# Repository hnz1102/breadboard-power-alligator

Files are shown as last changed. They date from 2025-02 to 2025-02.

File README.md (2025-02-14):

<div align="center">
  <h1><code>BREAD BOARD POWER ALLIGATOR</code></h1>
  <p>
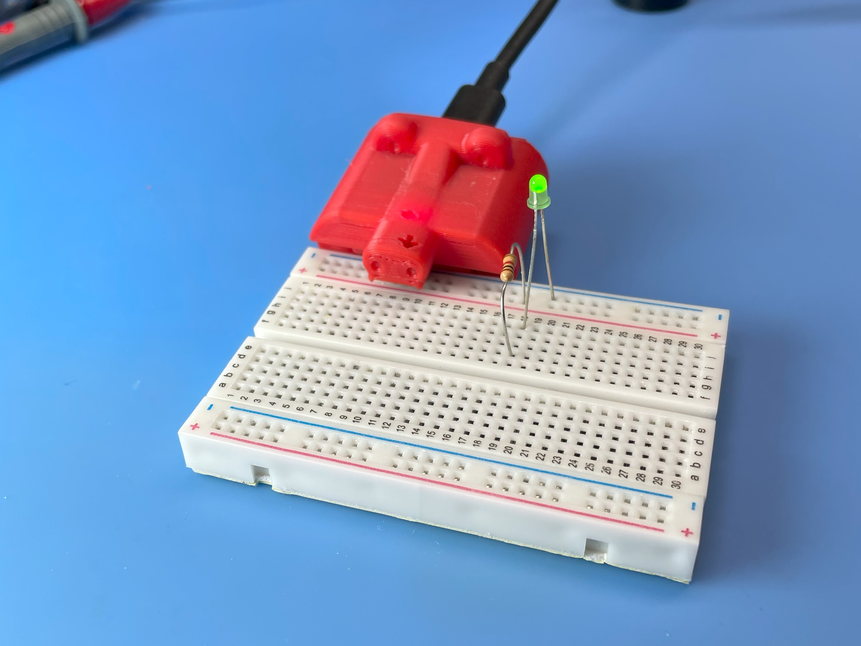
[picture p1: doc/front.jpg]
    
  </p>
</div>

# BREAD BOARD POWER ALLIGATOR : Power Supply for Bread-Board

This is power supplies for bread-board. They are designed to be used with a USB PD power supply. The output voltage is from 3.3V to 20V, and the output current is maximum 1A. The output voltage is fixed each adoptor. I made 6 adapters for bread-board power supply. The adapters are 3.3V, 5V, 9V, 12V, 15V, and 20V. The adapters are connected to the bread-board such an alligator clips. It is easy to set up the power supply for the bread-board. If you use a USB PD power supply, you can use over 9V output. If it is not USB PD, you can use only 3.3V or 5V.

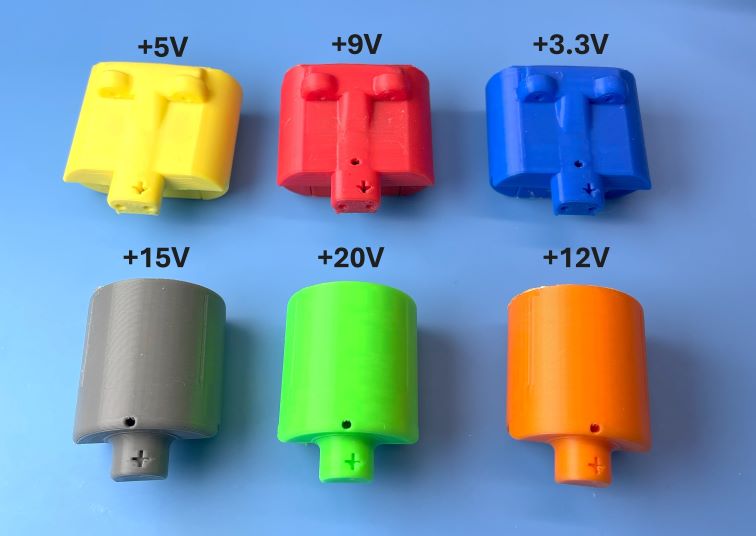
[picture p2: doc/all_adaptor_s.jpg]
All adapters


The PCB is designed by KiCad. The PCB is common to all adapters. 

## How to use
Just connect a USB PD power supply to the USB-C connector. Then, connect the adoptor to the bread-board. The output voltage is fixed each adoptor. If it turns on the power supply, the LED lights up. 

Be careful to connect the adoptor to the bread-board. The inside of the bread-board power line is +, so connect it so that the top is -. Also, be careful not to connect different adapters to the same bread-board.

## Schematic
[Schematic PDF File](doc/schematic.pdf)

Each adoptor has a different output voltage. The output voltage is determined by any of the following parts.

|Output Voltage|U102|D102|C101|C104|R103|R104|R105|R106|JP101|JP102|
|---|---|--|--|--|--|--|--|--|--|--|
|3.3V|AZ1117CH-3.3|CUS10F3D|DNP|10uF|1K|DNP|0|DNP|OPEN|SHUNT|
|5V|DNP|DNP|DNP|DNP|1K|DNP|DNP|DNP|SHUNT|SHUNT|
|9V|DNP|DNP|1uF|DNP|2K|1K|DNP|20K|SHUNT|OPEN|
|12V|DNP|DNP|1uF|DNP|2K|1K|DNP|47K|SHUNT|OPEN|
|15V|DNP|DNP|1uF|DNP|2K|1K|DNP|100K|SHUNT|OPEN|
|20V|DNP|DNP|1uF|DNP|2K|1K|DNP|200K|SHUNT|OPEN|

*1 DNP: Do Not Populate
*2 R107 is DNP for all adapters.

If you want to change the output voltage, you can change the parts of the table.
e.g If you want to change the output voltage to 1.8V or 2.5V, you can change the parts as follows.
|Output Voltage|U102|D102|C101|C104|R103|R104|R105|R106|JP101|JP102|
|---|---|--|--|--|--|--|--|--|--|--|
|1.8V|AZ1117CH-1.8|CUS10F3D|DNP|10uF|1K|DNP|0|DNP|OPEN|SHUNT|
|2.5V|AZ1117CH-2.5|CUS10F3D|DNP|10uF|1K|DNP|0|DNP|OPEN|SHUNT|

## PCB

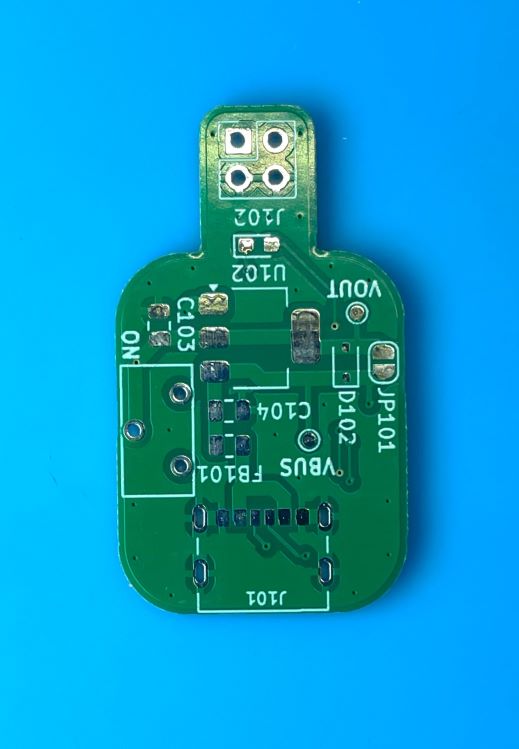
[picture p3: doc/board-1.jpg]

*3 In the photo, the PCB is designed to accommodate a Switch, but it was removed from the PCB layout because a compatible Switch could not be found.

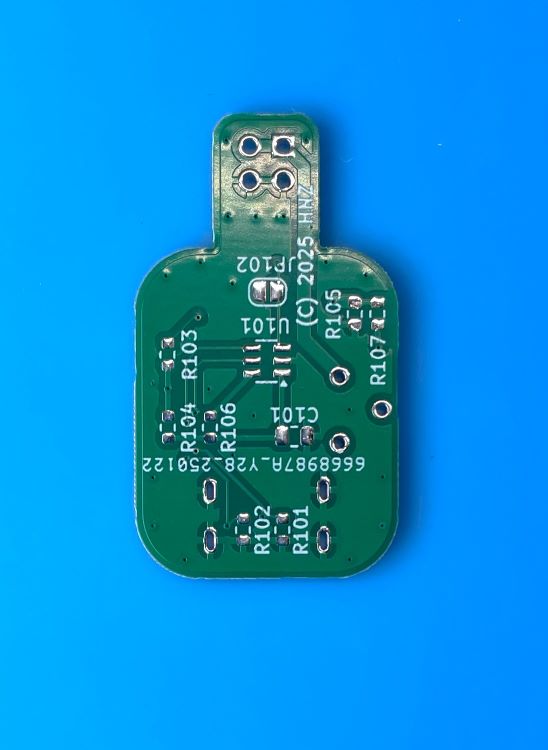
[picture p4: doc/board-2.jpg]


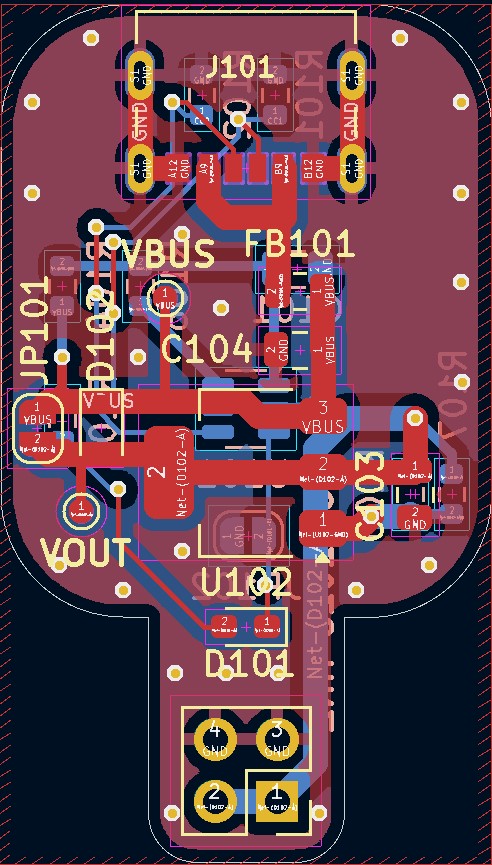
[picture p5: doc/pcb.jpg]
PCB Layout


# Container

There are STL data for 3D printer in the `stl` directory.
bottom.stl is the bottom of the container. upper-al-xx.stl is the upper of the container like alligator clips. upper-simple_xx.stl is the upper of the container like a battery form.

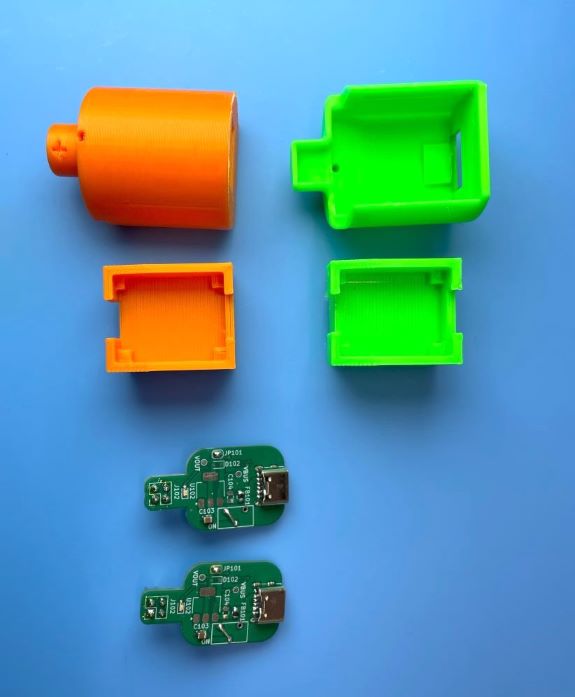
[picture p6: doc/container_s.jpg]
Container


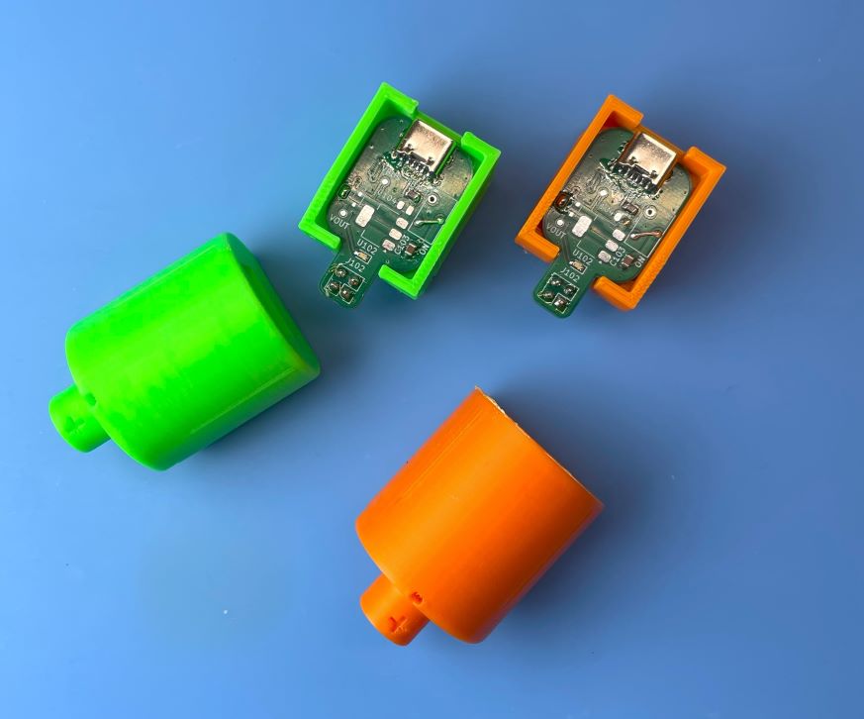
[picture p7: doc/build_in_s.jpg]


## LICENSE
Hardware Schematic Documents are licensed under CC-BY-SA V4.0.

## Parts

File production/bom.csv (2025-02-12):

Reference | Value | Footprint | Qty | digikey | distributor
C101 | 1uF/50V | Capacitor_SMD:C_0805_2012Metric | 1 | 311-1886-1-ND | https://www.digikey.com/en/products/detail/yageo/CC0805KKX7R9BB105/5195292
C103 | 22uF | Capacitor_SMD:C_0805_2012Metric | 1 | 311-1903-1-ND | https://www.digikey.com/en/products/detail/yageo/CC0805MKX5R8BB226/5195309
C104 | 10uF | Capacitor_SMD:C_0805_2012Metric | 1 | 311-1869-1-ND | https://www.digikey.com/en/products/detail/yageo/CC0805KKX5R8BB106/5195275
D101 | LED RED | LED_SMD:LED_0603_1608Metric_Pad1.05x0.95mm_HandSolder | 1 | 3147-B1931URO-20D000114U1930CT-ND | https://www.digikey.com/en/products/detail/harvatek-corporation/B1931URO-20D000114U1930/15910603
D102 | CUS10F30 | Diode_SMD:D_SOD-323 | 1 | CUS10F30H3FCT-ND | https://www.digikey.com/en/products/detail/toshiba-semiconductor-and-storage/CUS10F30-H3F/2753202
FB101 | MPZ2012S102ATD25 | Resistor_SMD:R_0805_2012Metric | 1 | 445-MPZ2012S102ATD25CT-ND | https://www.digikey.com/en/products/detail/tdk-corporation/MPZ2012S102ATD25/5040327
J101 | USB_C_Receptacle_PowerOnly_6P | Library:CUI_UJC-HP-3-SMT-TR | 1 | 2223-UJC-HP-3-SMT-CT-ND | https://www.digikey.com/en/products/detail/same-sky-formerly-cui-devices/UJC-HP-3-SMT-TR/12173295
J102 | PinHeader 02x02 | Connector_PinHeader_2.54mm:PinHeader_2x02_P2.54mm_Vertical | 1 | 2057-PH2-04-UA-ND | https://www.digikey.com/en/products/detail/adam-tech/PH2-04-UA/9830324
JP101 | SHUNT IT IF NO USE AZ117C | Jumper:SolderJumper-2_P1.3mm_Open_RoundedPad1.0x1.5mm | 1 | - | -
JP102 | SHUNT IT IF NO USE CH221K | Jumper:SolderJumper-2_P1.3mm_Open_RoundedPad1.0x1.5mm | 1 | - | -
R101,R102 | 5K1 | Resistor_SMD:R_0603_1608Metric | 2 | 311-5.10KHRCT-ND | https://www.digikey.com/en/products/detail/yageo/RC0603FR-075K1L/727268
R103 | 2K | Resistor_SMD:R_0603_1608Metric | 1 | 311-2.0KGRCT-ND | https://www.digikey.com/en/products/detail/yageo/RC0603JR-072KL/726726
R104 | 1K | Resistor_SMD:R_0603_1608Metric | 1 | 311-1.00KHRCT-ND | https://www.digikey.com/en/products/detail/yageo/RC0603FR-071KL/726843
R105 | 0/ADJ-R2 | Resistor_SMD:R_0603_1608Metric | 1 | 311-0.0GRCT-ND | https://www.digikey.com/en/products/detail/yageo/RC0603JR-070RL/726675
R106 | 200K | Resistor_SMD:R_0603_1608Metric | 1 | 311-200KHRCT-ND | https://www.digikey.com/en/products/detail/yageo/RC0603FR-07200KL/727044
R107 | ADJ-R1 | Resistor_SMD:R_0603_1608Metric | 1 | - | -
TP101 | VOUT | TestPoint:TestPoint_Pad_D1.0mm | 1 | - | -
TP102 | VBUS | TestPoint:TestPoint_Pad_D1.0mm | 1 | - | -
U101 | CH221K | Package_TO_SOT_SMD:SOT-23-6 | 1 | - | https://jlcpcb.com/partdetail/WCH_Nanjing_Qinheng-CH221K/C5125736
U102 | AZ1117C | Package_TO_SOT_SMD:SOT-223-3_TabPin2 | 1 | 497-17239-1-ND | https://www.digikey.com/en/products/detail/stmicroelectronics/LD1117S33TR/585766

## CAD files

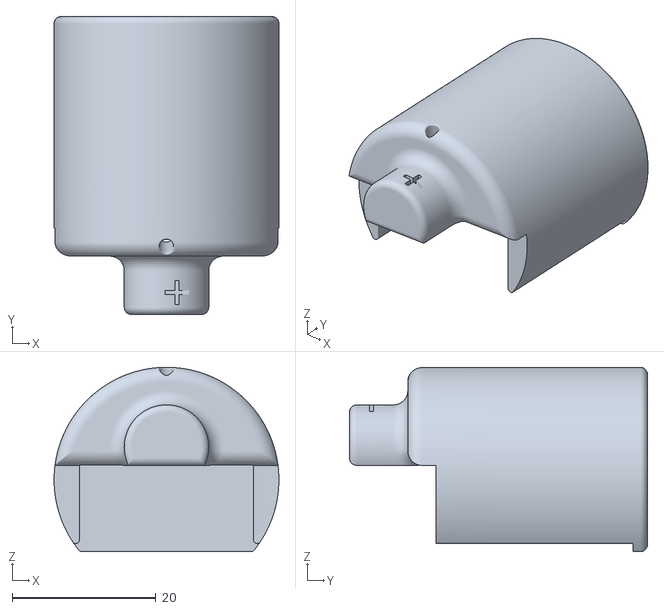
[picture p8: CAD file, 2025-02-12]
stl/upper_simple_15v.stl
31.2 x 41.4 x 25.6

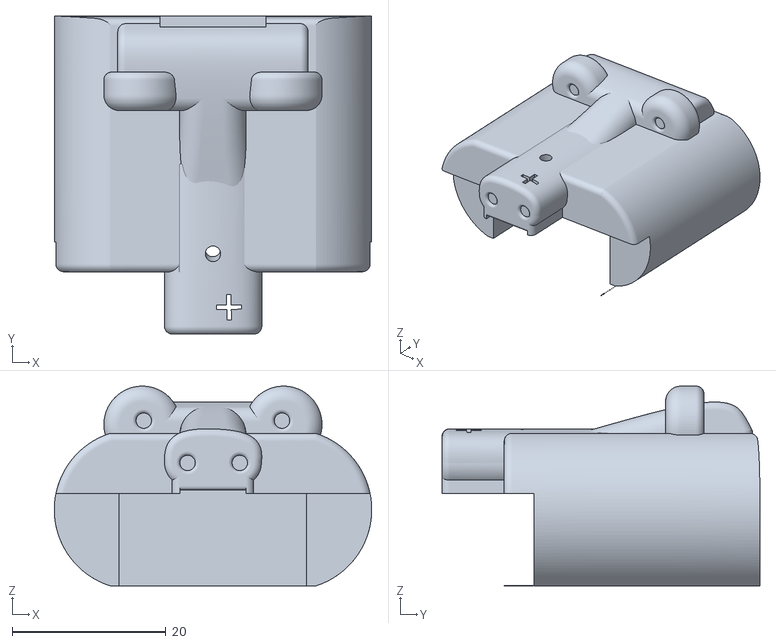
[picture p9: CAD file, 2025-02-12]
stl/upper-al-12v.stl
41.3 x 41.4 x 26.0

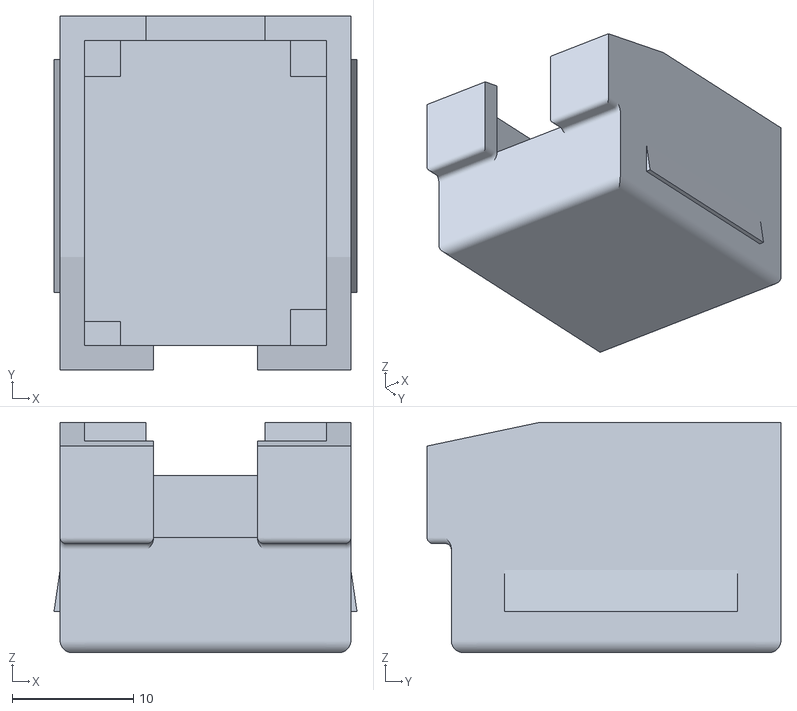
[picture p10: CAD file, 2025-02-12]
stl/bottom.stl
25.0 x 29.2 x 19.0

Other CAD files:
stl/upper_simple_12v.stl
stl/upper-simple-5v.stl
stl/upper-simple-3.3v.stl
stl/upper-simple-9v.stl
stl/upper-al-20v.stl
stl/upper-al-9v.stl
stl/upper-al-15v.stl
stl/upper-al-3.3v.stl
stl/upper-simple-20v.stl
stl/upper-al-5v.stl

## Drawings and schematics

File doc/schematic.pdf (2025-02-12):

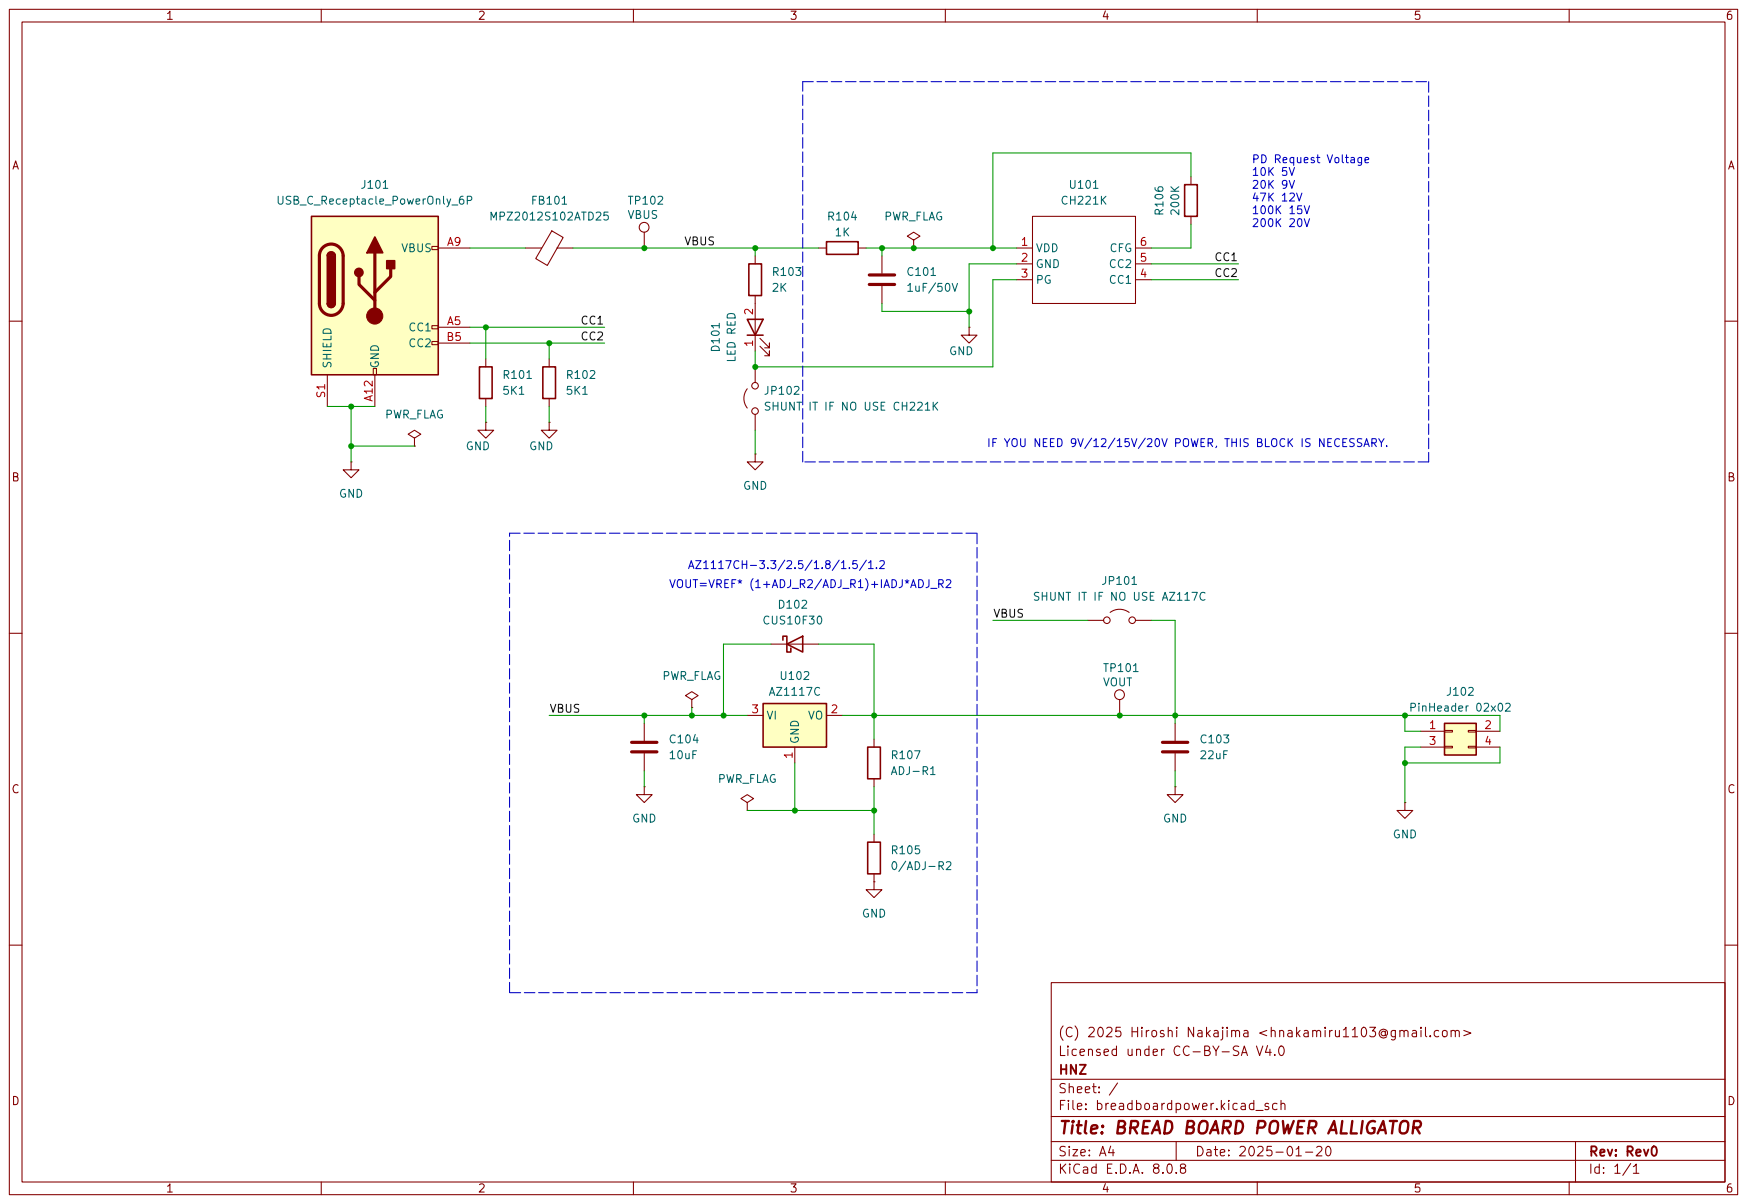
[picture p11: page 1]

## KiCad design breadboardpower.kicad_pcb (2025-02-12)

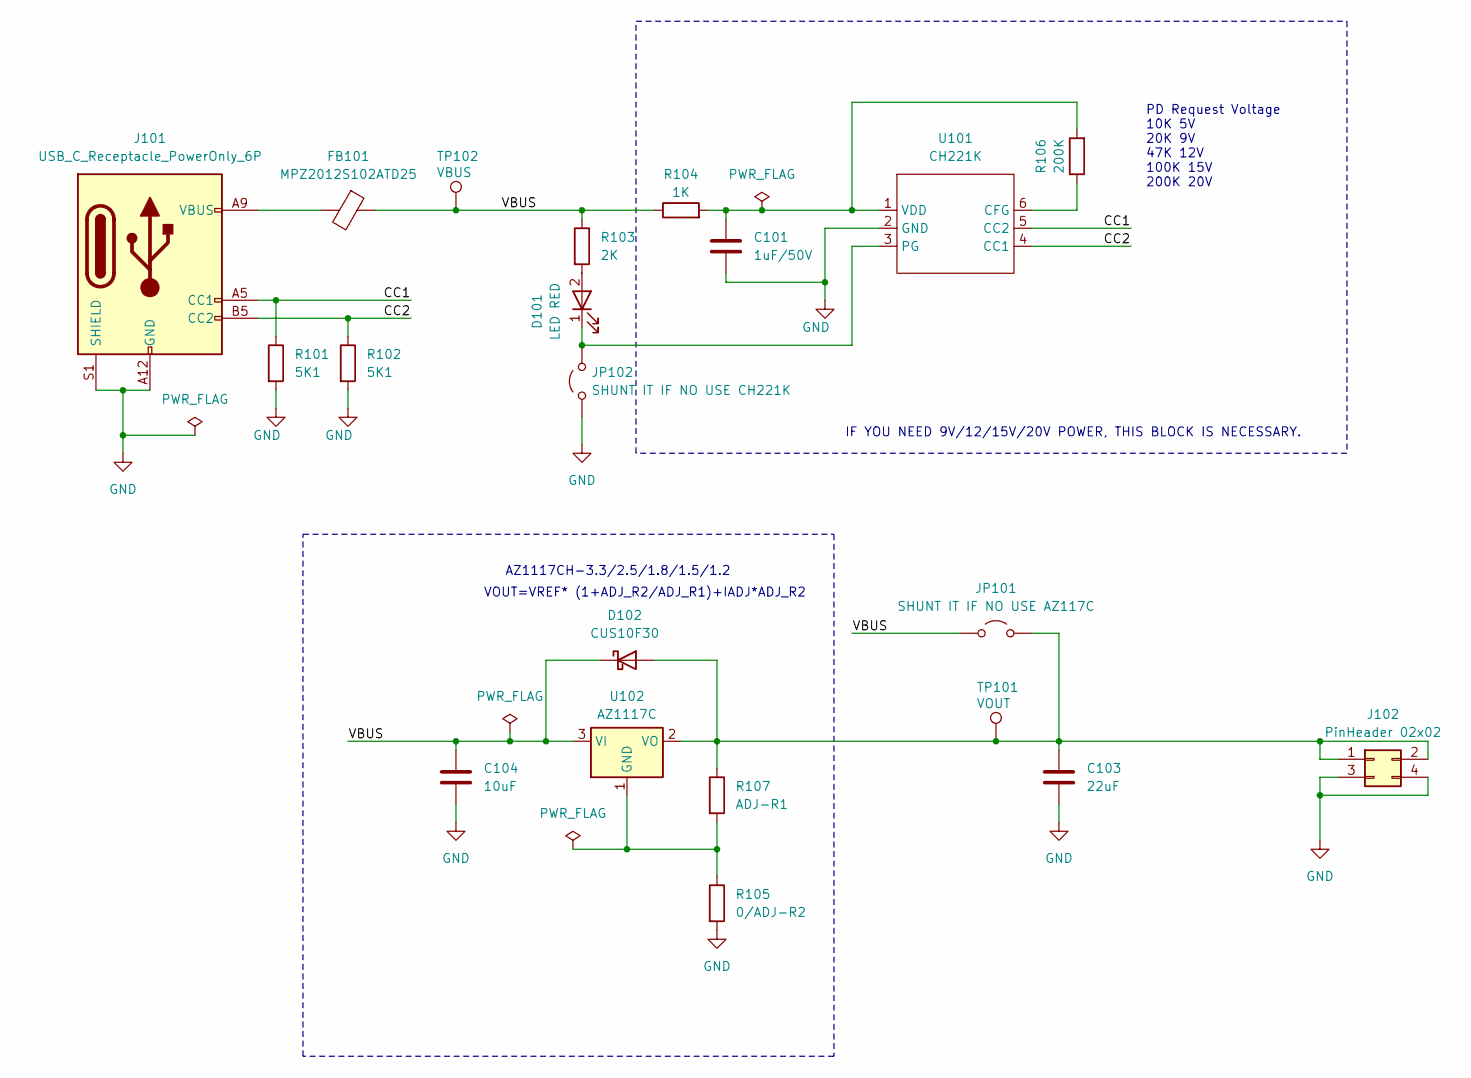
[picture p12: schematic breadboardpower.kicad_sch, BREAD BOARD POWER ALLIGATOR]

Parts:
C101: 1uF/50V; C_0805_2012Metric; digikey 311-1886-1-ND
C103: 22uF; C_0805_2012Metric; digikey 311-1903-1-ND
C104: 10uF; C_0805_2012Metric; digikey 311-1869-1-ND
D101: LED RED; LED_0603_1608Metric_Pad1.05x0.95mm_HandSolder; digikey 3147-B1931URO-20D000114U1930CT-ND
D102: CUS10F30; D_SOD-323; digikey CUS10F30H3FCT-ND
FB101: MPZ2012S102ATD25; R_0805_2012Metric; digikey 445-MPZ2012S102ATD25CT-ND
J101: USB_C_Receptacle_PowerOnly_6P; CUI_UJC-HP-3-SMT-TR; digikey 2223-UJC-HP-3-SMT-CT-ND
J102: PinHeader 02x02; PinHeader_2x02_P2.54mm_Vertical; digikey 2057-PH2-04-UA-ND
JP101: SHUNT IT IF NO USE AZ117C; SolderJumper-2_P1.3mm_Open_RoundedPad1.0x1.5mm
JP102: SHUNT IT IF NO USE CH221K; SolderJumper-2_P1.3mm_Open_RoundedPad1.0x1.5mm
R101, R102: 5K1; R_0603_1608Metric; digikey 311-5.10KHRCT-ND
R103: 2K; R_0603_1608Metric; digikey 311-2.0KGRCT-ND
R104: 1K; R_0603_1608Metric; digikey 311-1.00KHRCT-ND
R105: 0/ADJ-R2; R_0603_1608Metric; digikey 311-0.0GRCT-ND
R106: 200K; R_0603_1608Metric; digikey 311-200KHRCT-ND
R107: ADJ-R1; R_0603_1608Metric
TP101: VOUT; TestPoint_Pad_D1.0mm
TP102: VBUS; TestPoint_Pad_D1.0mm
U101: CH221K; SOT-23-6
U102: AZ1117C; SOT-223-3_TabPin2; digikey 497-17239-1-ND

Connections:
/CC1: J101.A5 (CC1), R101.1, U101.5 (CC2)
/CC2: J101.B5 (CC2), R102.1, U101.4 (CC1)
/VBUS: C104.1, D102.1 (K), FB101.1, JP101.1 (A), R103.1, R104.1, TP102.1, U102.3 (VI)
GND: C101.2, C103.2, C104.2, J101.A12 (GND), J101.B12 (GND), J101.S1 (SHIELD), J102.3, J102.4, JP102.1 (A), R101.2, R102.2, R105.2, U101.2 (GND)
unnamed: D101.2 (A), R103.2
unnamed: D101.1 (K), JP102.2 (B), U101.3 (PG)
unnamed: C103.1, D102.2 (A), J102.1, J102.2, JP101.2 (B), R107.1, TP101.1, U102.2 (VO)
unnamed: FB101.2, J101.A9 (VBUS), J101.B9 (VBUS)
unnamed: R106.1, U101.6 (CFG)
unnamed: C101.1, R104.2, R106.2, U101.1 (VDD)
unnamed: R105.1, R107.2, U102.1 (GND)

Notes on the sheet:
VOUT=VREF* (1+ADJ_R2/ADJ_R1)+IADJ*ADJ_R2
IF YOU NEED 9V/12/15V/20V POWER, THIS BLOCK IS NECESSARY.
PD Request Voltage 10K 5V 20K 9V 47K 12V 100K 15V 200K 20V
AZ1117CH-3.3/2.5/1.8/1.5/1.2

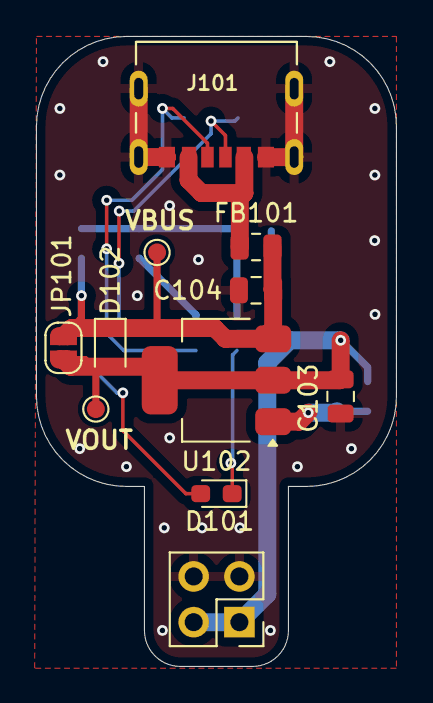
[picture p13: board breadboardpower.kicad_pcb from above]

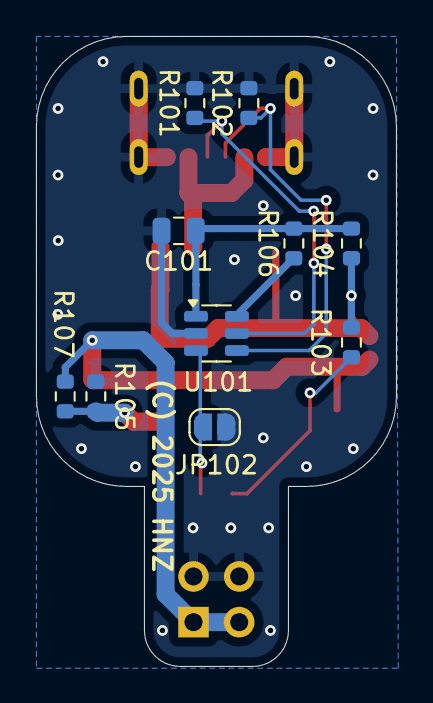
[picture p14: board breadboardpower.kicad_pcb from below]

Board: 2 copper layers, 20.0 x 35.0 mm, 21 parts (10 on the bottom side), 11 nets.

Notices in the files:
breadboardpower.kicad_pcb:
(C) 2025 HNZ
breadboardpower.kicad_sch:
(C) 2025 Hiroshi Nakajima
